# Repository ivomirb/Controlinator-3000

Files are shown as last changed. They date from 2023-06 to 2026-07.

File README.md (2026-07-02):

# Controlinator 3000
CNC handheld pendant for OpenBuilds CONTROL

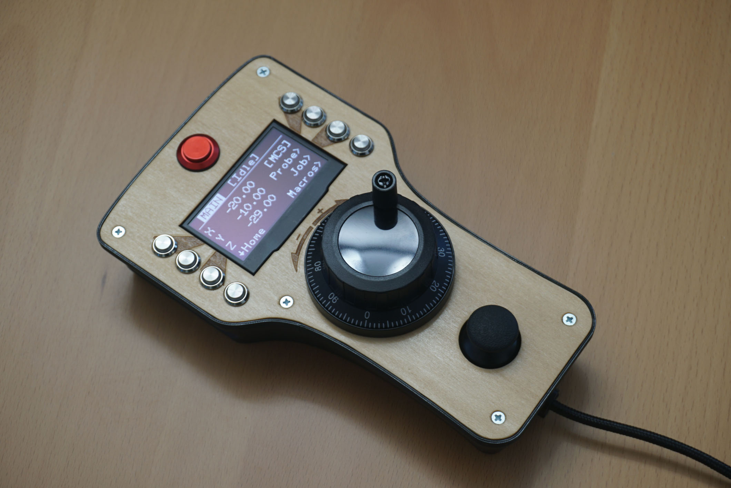
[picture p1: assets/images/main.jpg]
The pendant


## Main features

* Display current status and position
* Switch between machine and work coordinates
* Fast XY jogging with the joystick
* Precise jogging of a single axis with the handwheel
* Safe jog limits in all directions
* Start and control jobs, adjust feeds and speeds on the fly
* Run custom macros
* Probe Z
* Measure tool length
* Extensive configuration settings

## Documentation

How to make it: [/docs/hardware.md](/docs/hardware.md)

How to program it: [/docs/software.md](/docs/software.md)

How to configure it: [/docs/settings.md](/docs/settings.md)

How to use it: [/docs/usage.md](/docs/usage.md)

Tool length probing: [/docs/tool_length.md](/docs/tool_length.md)

Issues and future developments: [/docs/future.md](/docs/future.md)

## Versions

### 1.5 - July 2026
* Added support for Arduino Nano R4
* The joystick can be used on the probing screen to nudge the XY position
* Holding down Z on the jog screen moves up
* NOTE: Requires OpenBuilds v1.0.371 or later

### 1.3 - June 2026
* Few bug fixes
* Job actions (run, pause, stop) are logged to the console
* Improved diagnostics for disconnects and freezes
* Randomize tool probe location to reduce surface wear

### 1.2 - August 2025
* New option to use the probe to measure Z height without changing the work coordinate system
* A watchdog system to detect lockups and automatically restart and reconnect
* Few bug fixes

### 1.1 - July 2023
* Initial public version

## Few videos of the pendant in action
Higher-quality versions of these videos can be viewed near the bottom of the OSHWLab page: https://oshwlab.com/ivo1/controlinator3000

https://github.com/ivomirb/Controlinator-3000/assets/85206280/82b60430-23b6-44c3-90c5-cbde8dea85b0

https://github.com/ivomirb/Controlinator-3000/assets/85206280/08690167-5684-4be5-bea4-8ef6c2ea5f81

https://github.com/ivomirb/Controlinator-3000/assets/85206280/ce256c9c-9cf2-4aa7-af1b-1ccd04ead18f

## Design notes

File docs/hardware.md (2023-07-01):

# Controlinator 3000 - Hardware

Long story short, make the PCB, add a microcontroller, a display, some buttons, a handwheel and a joystick. Place them inside the provided 3D model. Upload the C++ code to the microcontroller and use the Javascript code as a macro for the OpenBuilds Control software.

You can use Arduino Nano, Arduino Nano Every with 4809 chip, or Arduino Nano clone with 4808. The last two have extra memory, which enables better performance.  
Schematic: https://easyeda.com/editor#id=6772a173c7f747c4bd99ec3e6c18ea2e  
PCB: https://easyeda.com/editor#id=7d417a9957d24bc288f2ec065d723912  
Source code: https://github.com/ivomirb/Controlinator-3000/tree/master/Source  
3D models: https://github.com/ivomirb/Controlinator-3000/tree/master/Models

## Components

**Microcontroller:** You need one compatible with Arduino Nano. There are few options with different capabilities. Both 30-pin and 34-pin packages are supported. See the next section for more details.

**Display:** A 2.4” OLED display compatible with the I2C interface. This is the one I used: https://www.aliexpress.us/item/3256805055000425.html  
**Note:** This particular model requires hardware modification to work correctly. Remove the D2 diode and replace it with a straight wire. Without this it won’t send the ACK signal and it will only work in software mode, which is slow. In my experience most similar screens come in SPI mode out of the box and require hardware modifications to convert to I2C. It is possible to redesign the pendant to use SPI, with some modifications to the PCB design and using an extra digital pin

**Handwheel:** A manual pulse generator like this: https://www.aliexpress.us/item/2251832666651590.html  
You need the 5V version to be compatible with the Arduino. The 4-pin version works best. If you have the 6-pin version it will also work, just ignore the bottom two connectors.  
I actually ended up using the plastic version from here: https://www.aliexpress.us/item/3256801157578368.html  
It is half the weight of the metal wheel (80 grams vs 160), reducing the overall weight of the pendant by 20%

**Joystick:** I am using a regular Arduino joystick that you can find everywhere. Here’s one example: https://www.aliexpress.us/item/2251832496927403.html

**Buttons:** You need eight 8mm buttons. They are the smallest ones I could find that still feel like regular buttons. Also one 16mm button for the Self Destruct at the top. It can be red for dramatic effect  
https://www.aliexpress.us/item/3256801900884791.html  
https://www.aliexpress.us/item/3256804994691187.html

**Optional reset switch:** You can mount a tiny reset switch that is accessible through a small hole in the front. The existing mount is for this type of switch: https://www.amazon.com/gp/product/B073TYWX86

You can find the schematics here: https://easyeda.com/editor#id=6772a173c7f747c4bd99ec3e6c18ea2e  
Shoutout to EasyEDA – I’ve never designed a PCB before, but after only watching a [10-minute video](https://www.youtube.com/watch?v=MsdJgEinb34) I was able to make my own circuit, edit a custom footprint for the 34-pin Arduino variant, design the dual layer board, and order it from the JLCPCB factory, all in two hours. With the available coupons, I got 15 copies essentially for free.  
(not a sponsored statement – just happy with the service and the end product)

## Microcontrollers
There are few choices that are supported

1. A regular Arduino Nano with ATmega 328P. It has 32K ROM and 2K RAM. This is what I used throughout most of the development

2. Arduino Nano Every, with ATmega 4809 chip. It has 48K ROM and 6K RAM. The extra memory allows for the display to be mirrored in RAM and to be updated only as needed. This greatly improves the framerate and responsiveness.  
I do not own one and haven’t tested it, however I’m pretty confident it would work, since it is very similar to 4808

3. An Arduino Every clone with ATmega 4808, like this one: https://www.aliexpress.us/item/3256804681280426.html  
It is similar to Arduino Every, however has 4 extra pins, including a UPDI connection that allows programming it without interfering with the USB port. This is what I ended up using in the final version.  
**Note:** While this model has the same general pinout as Arduino Nano, there are subtle differences. The most notable is that the SCL and SDA pins needed to drive the display are on different pins – D4 and D5 instead of A4 and A5 on the Nano. The PCB can be configured to work with one or the other. See below

Other devices may also work if they have the right capabilities and compatible pinout. You may need to edit Config.h to be able to compile the source code.

## Assembly
* If you have a 30-pin Arduino Nano or Nano Every, use the middle 30 pins. Ignore the 4 corner pins. For 34-pin versions use the entire footprint

* You can solder the Arduino directly to the PCB or use two 17-pin female headers to make it removable. I opted for removable so I can easily experiment during development

* Under the Arduino there are 6 pads that route the SCL and SDA signals for the display. Use two pieces of wire to bridge the middle pads to the left or to the right, depending on your microcontroller. Standard Arduino Nano and Every use the A4 and A5 pins (connect middle and right). The 4808 version uses D4 and D5 (connect middle and left). Check the documentation for your exact device.
I am using a 3x2 right-angle pin header, which allows me to select one or the other with jumpers during development

* **Optional step:** 34-pin versions have an extra programing pin in the top-left. If you want to use it, add a 4.7K resistor to R1 and a 2-pin header to UPDI. Look up “UPDI” online to find tutorials how to use it. If your programming circuit already includes a resistor, replace R1 with a piece of wire

* **Optional step:** Normally the Arduino would reset if a serial connection is initiated from the PC. This is to allow it to be programmed, however it causes a few seconds delay before it is operational. To avoid that, add a 100nF capacitor to C1 and a 2-pin header to JMP. Then use a jumper on the header to disable the reset. Remove the jumper during programming. If you only use the UPDI for programing, you may short the JMP pads with a piece of wire permanently

* **Optional step:** RST is for wiring an external reset switch. In my case I have a tiny switch at the front of the pendant, which can be pushed through a small hole with a paperclip

* DISP is for wiring the display. The pins are GND, 5V, 3.3V, SCL, SDA. Use either the 5V or the 3.3V pin depending on the power requirements for your particular model. The display I have worked with either voltage. Only use one of the two – don’t short them together

* Connect a 4x2 right-angle pin header to BTN1..4. This is for the buttons on the left side of the pendant. Right-angle headers allow for a slimmer profile

* Connect a 5x2 right-angle pin header to BTN5..9. This is for the 4 buttons on the right side and for the big Abort button at the top. You can also use a 6x2 header, which exposes pin D11 for expansions

* MPG is for the handwheel

* JOY is for the joystick. The X and Y are marked according to the joystick device, but are reversed in software to account for the mounting orientation

* You can technically solder everything permanently, but I prefer to have cables that are detachable from one end to ease the assembly and disassembly. I have the display and joystick wires soldered to the board with Dupont connector on the other end. The handwheel wires are soldered to the board with spade connectors on the other end. The button wires are soldered to the buttons and connect to the corresponding headers on the board

When assembled, the PCB should look like this:

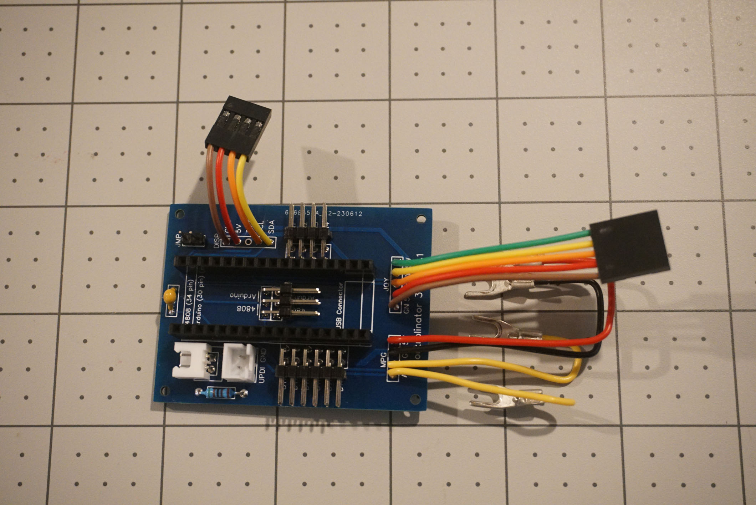
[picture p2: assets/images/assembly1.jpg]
Assembled PCB


You can find the 3D printed parts here, both as STL and STP: https://github.com/ivomirb/Controlinator-3000/tree/master/Models

You can use the face plate as is, or print it 1.5mm thinner and add a layer of thin plywood on top. I myself used basswood sprayed with shellac. Use the face_plate.svg file for the shape.

There are 2 versions of the PCB bracket – one for a prototype 40x60mm board and one for the custom PCB from EasyEDA. The hole spacing is different. The bracket assumes that the display connectors are on the right side. You will need to modify the model if your screen has its pins someplace else.

The large parts can be printed at 0.3mm layer height and the small pieces at 0.1. I use PETG for everything. I find it durable and it has a bit of a flex that holds screws well.

Attach the PCB to the top of the bracket using 2mm machine screws and 4 of the spacers. Then screw the screen to the bottom and connect the cable.

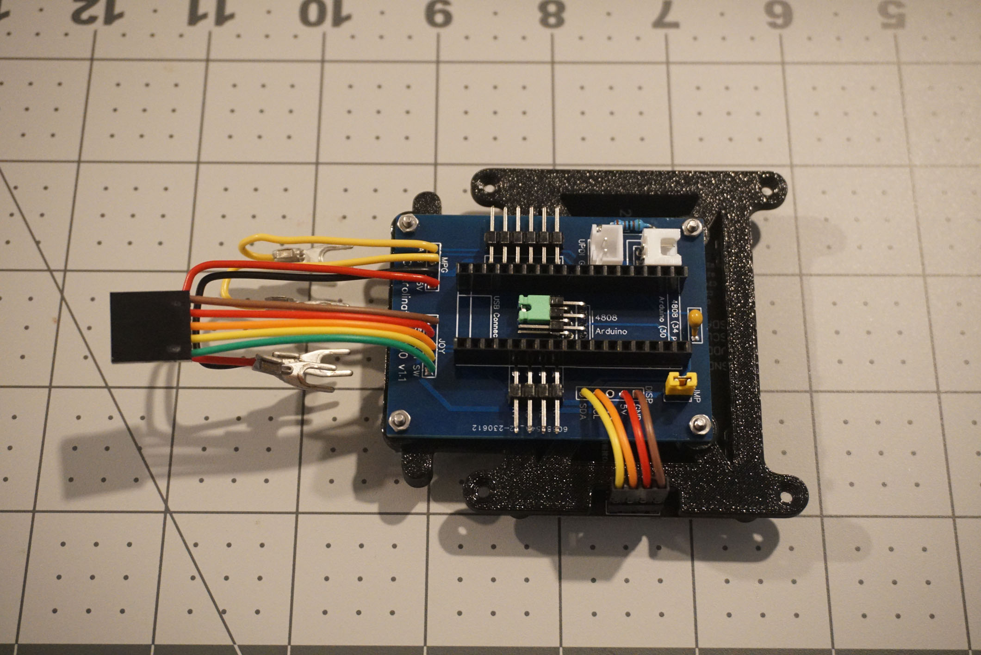
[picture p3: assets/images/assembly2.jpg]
Assembled PCB and display


The joystick and the screen attach with 2mm wood screws. I used these: https://www.amazon.com/gp/product/B0768H7HTR
The cable clamps and the final assembly of the box use standard 3/4" #4 wood screws.
The reset switch uses 2mm machine screws and threaded inserts that are embedded in the plastic.

You can use different size screws, but you may need to adjust the holes in the 3D models to match.

You will also need a USB cable of some sort. I recommend 6-10 feet long. It needs to match the connector of your microcontroller. It could be micro-USB, mini, or even USB-C.

The cable is held in place by the two halves of the cable holder, connected with M3 screws and 5.5mm square nuts.

Here’s everything put together:

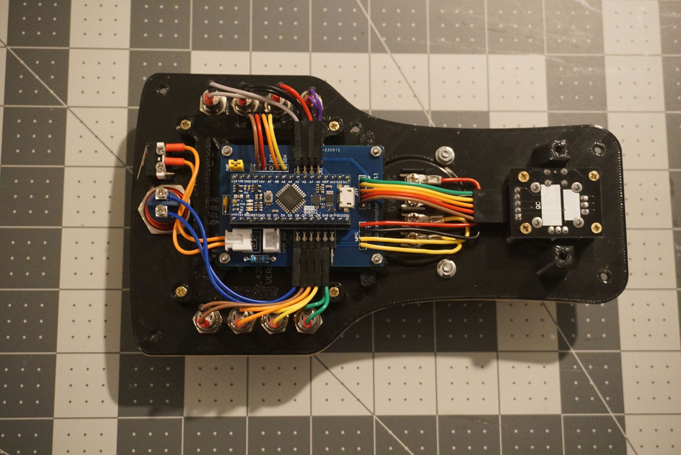
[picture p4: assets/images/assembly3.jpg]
Assembled pendant


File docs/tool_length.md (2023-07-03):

# Controlinator 3000 - Tool length

When a job uses multiple tools, you have to ensure that the Z position is preserved from one tool to the next. Probing for Z is not always an option, and is error-prone. The best way is to adjust the tool length offset (TLO) as the tool is replaced.

The TLO implementation in Grbl is not that good. You can set the value, however it is lost after a soft reset, which can happen quite often. There is very little indication when that happens.

The pendant software uses different approach to adjust the Z offset when the tool is changed. It requires a tool sensor to be installed on the CNC. A tool sensor is nothing more than a Z probe at a fixed location. In the pendant settings, enter the X and Y location of the sensor and select the probing method. The settings are similar to the Z probe.

You start your job as normal with the first tool. Use the regular Z probe to measure your work piece. Before switching to the second tool, select the Probe option from the main menu on the pendant, then select "Probe Ref Tool". You will use the tool sensor to measure the absolute height of the current tool. It will become the reference for all future tools.

Replace the tool in the spindle, and then select "Probe New Tool". The pendant will measure the new tool, determine the difference in the length compared to the reference tool, and will apply the difference to the current Z offset.

If you ever forget to probe the next tool and lose your reference, you will need to select "Probe Ref Tool" again. As long as you have a tool that matches your current work coordinate system, you can successfully use it as a reference for future tools.  
**Note:** the reference height will be lost if the OpenBuilds software restarts. Again, just make sure you have correct work Z, and set the current tool as a reference.

Since the pendant software will jog to the tool sensor location in machine coordinates, it requires that the machine is homed. If the pendant thinks that the machine has lost its homing position, it will show a warning message. You can ignore it if you think it is safe.

## Tool Sensor Variants

There are different ways to create a tool sensor. The important thing is that the sensor doesn't move between measurements.  
The sensor will be connected in parallel with the regular Z probe, meaning it will trigger the Z probe signal when the tool touches the sensor.

Here are few possible ways to do it:

1. Use a regular Z probe plate that is securely attached somewhere. You will need to connect the alligator cable to your spindle every time you measure the tool.

2. Use an off the shelf tool sensor, maybe something like this one: https://www.amazon.com/RATTMMOTOR-Automatic-Normally-Setting-Engraving/dp/B08LK93NTC  
I have not tried such a device myself. Those are nice as they have a secondary contact that is triggered if the button is pushed too far. You can wire it to the E-Stop to shut down everything before any damage is done. There is also an option to connect compressed air to blow the chips off of the tool during probing.

3. Make one yourself using a push button. This is what I ended up with.  
The advantage of using a button over Z plate is that you don't need to connect the alligator cable. You can have the sensor out of the way in the far corner of the machine.
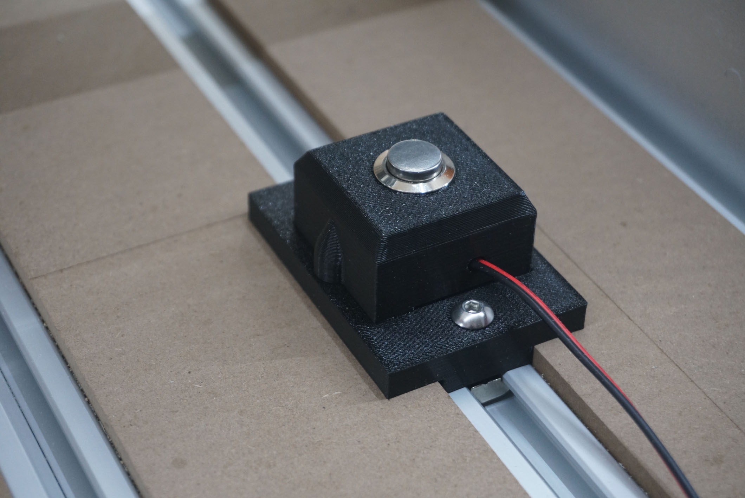
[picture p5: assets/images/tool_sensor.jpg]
Tool sensor


You can find the 3D models here: https://github.com/ivomirb/Controlinator-3000/tree/master/Models  
There is a top and bottom part, connected with M3 threaded inserts.  
It uses a 16mm push button like this one: https://www.aliexpress.us/item/2251832680756878.html  
A larger button will work even better because it will be able to handle larger tools, like a spoilboard flattening cutter.

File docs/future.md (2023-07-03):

# Issues and future developments

There are a few things that can be improved in future versions. In no particular order:

There is a known problem where jogging with the wheel might occasionally stall. This happens when Grbl enters a Run state instead of Jog state after a jog command. The next jog command fails, because jog commands are not allowed during the Run state.  
At this time I don't know if this is a bug in Grbl or something my code is doing wrong.

You can use buttons with built-in lights. This way the buttons that are inactive can be turned off, making it easier to associate a button with its label, even if they are not exactly aligned. There aren’t enough pins to control each light individually, however an 8-bit shift register like 74HC595 can be used to drive 8 LEDs with only 3 digital pins.

I would have liked a handwheel with fewer number of clicks per rotation for greater precision. The commonly available optical rotary encoders have 100 clicks. Even the “25 pulses per rotation” models still have 100 mechanical clicks, which is kind of useless.

A move from 8-bit Arduino to a more powerful microcontroller like ESP32 can improve the frame rate and responsiveness. A faster chip could be able to drive a larger TFT screen as well. They usually run at 3.3V, so some extra circuitry will be needed to interface with the 5V handwheel signal.

ESP32 boards come with Wi-Fi and other connectivity features, opening the possibility for a wireless pendant.

A buzzer could be added to warn about dangerous operations, inform of alarms, or confirm a button press. The PCB exposes pin D11 for such extensions.

The commonly available small joysticks have a very large outer dead zone. Basically, pushing the stick half-way maxes out the output and pushing it further doesn’t have any effect. I tried comparing samples from different suppliers and they all have the same problem. Likely they all use the same potentiometers. There may be better models out there. Possibly a higher-quality joystick can be salvaged from a game controller.

Instead of a handheld pendant, you may create a box that is attached to your CNC permanently. Change the layout of the controls to serve your design.

Currently the pendant is only compatible with OpenBuilds Control. It is possible to port the Javascript macro to other platforms that supports plugins. For example UGS can have plugins written in Java and bCNC can be extended with Python.

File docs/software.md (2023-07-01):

# Controlinator 3000 - Software

The source code can be found here: https://github.com/ivomirb/Controlinator-3000  
It is published under the MIT public license.

All code is included except for the U8G2 library. You will need to install it separately in the Arduino IDE.  
If you are using a different pulse encoder wheel, you might need to install this library as well: https://github.com/gfvalvo/NewEncoder  
The Controlinator source code contains a trimmed-down version of that library that is limited to support one type of wheel devices.

Compile the code, and then upload it with the USB cable or the UPDI port. Be careful of the polarity when connecting the UPDI. If you plug it in backwards, the microcontroller will likely be safe because of the resistor, however your programmer device will be shorted to ground and may get damaged.

On the OpenBuilds side, create a new Javascript macro and paste the contents of PendantMacro.js inside it. Set the macro to auto-start and then restart OpenBuilds from the tray icon.

## Javascript settings
At the top of the Javascript file you will find a few values to fine tune the behavior. Read the comments and decide if you wish to change them.

## C++ settings
Look at the Config.h file for a few available settings. You can configure the code based on the available memory and what kind of performance you are looking for.

## Pendant emulator

The emulator is a Desktop application that emulates the physical controls of the device and shares the majority of the code with the microcontroller. This allows for faster development using Visual Studio as editor and debugger.

The emulator also contains a piece of code that generates font.h from the font bitmap. You need to run it if you change the font or add more special symbols.

You will need to establish a serial connection between OpenBuilds and the emulator. I used a software called “HHD Virtual Serial Port Tools” to create a pair of connected ports COM13 and COM14. The emulator runs on COM14 (hard-coded in Serial.cpp) and the Javascript macro connects on COM13.  
There is another software “com0com” which should provide similar functionality, though I was unable to get it to work.

An even more lazy solution is to eliminate the CNC altogether. I uploaded a version of Grbl onto a standalone Arduino. OpenBuilds recognizes it as a valid machine. You can use the 3d view and other controls in OpenBuilds to monitor the current state of that virtual CNC.

Of course, emulation is not the same as the real thing, and final testing should be done with the actual pendant and a real CNC machine. But it is quite sufficient for building the user interface and for coding the first pass of the functionality.

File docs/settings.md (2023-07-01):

# Controlinator 3000 - Settings

Once the macro is running, it will add a Pendant button to the toolbar. From there you can connect the device, disconnect it, and edit the settings.

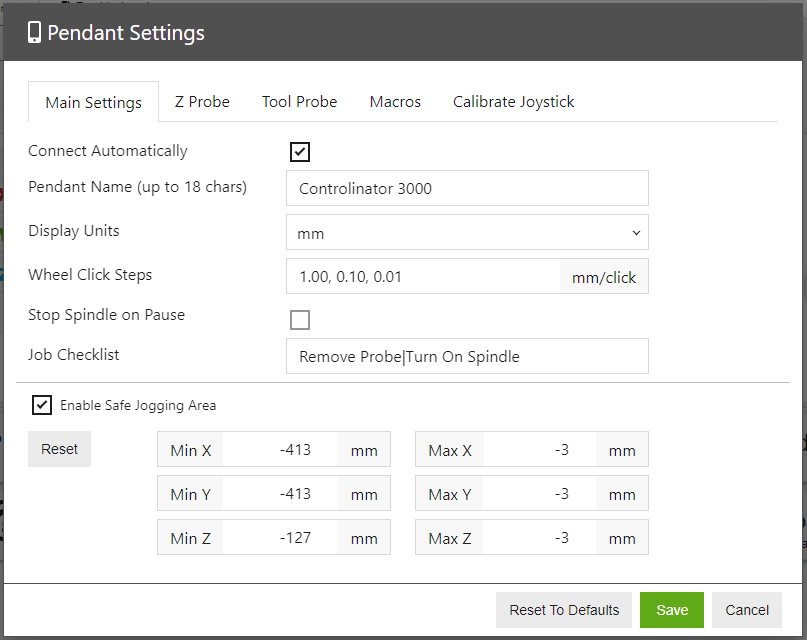
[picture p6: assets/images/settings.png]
Pendant settings


## Main Settings
**Connect Automatically** – check it if you want the pendant to auto-connect when OpenBuilds starts up

**Pendant Name** – set a name to be displayed on the pendant’s title screen. This can only be edited when the pendant is connected. The name is stored in the pendant’s EEPROM

**Display Units** – select if the pendant display should show the coordinates in inches or millimeters. It also affects the units for the wheel jog rate. It doesn’t change any other units in the pendant settings, which area always in mm

**Wheel Click Steps** – enter a list of movement distances for each click of the hand wheel. You can cycle between them using the Step button on the pendant. They don’t necessarily need to be in order. Pick an order that works for you, assuming that the first value in the list will be selected on startup

**Stop Spindle on Pause** – when this is enabled, pausing a job from the pendant (but not from the OpenBuilds toolbar) will automatically stop the spindle. This is done by triggering the door alarm in Grbl. Depending on the Grbl configuration, it may also raise the spindle to the park height. When you resume the job, the spindle will spin up for 4 seconds before it starts to move

**Jog Checklist** – enter up to 3 reminders to be shown on the pendant when you start a job. You will need to click the corresponding button to check off each one before you can continue

**Enable Safe Jogging Area** – this allows you to set an area in machine coordinates that is considered safe for jogging. Movement with the handwheel or the joystick will keep the machine inside the safe range

## Z Probe
**Z Probe Sequence** – select from “Single Pass”, “Dual Pass” or “Use default dialog”. Single and Dual pass allow you to select the travel distance and feed rate for the probe operation. Dual pass does 2 probings at different feed rates to improve accuracy.
When “Use default dialog” is selected, initiating a probe operation from the pendant will open the default dialog in OpenBuilds. It will allow you to use the extra settings for more complicated probing operations that are not available via the pendant alone. Of course, you will need to interact with the PC to access the extra settings

**Down Jog Speed** – select an override % rate for lowering the tool when the Z Down button is pressed on the pendant. Pick a speed that allows you to get close to the probe safely without running into it. The Z Up button is always at full speed because it is considered safe to go up

**Plate Thickness** – enter the thickness of your Z probe plate

**Use Exact Probe Result** – when probing, after the tool touches the probe, it would continue to travel for a few more steps before it stops. Open Builds and most other Grbl software use the final stop height. Check this box to use the original touch height instead. It can be more accurate

**Seek/Retract** – enter the travel distance and feed rate for each of the phases of the Z probing sequence

## Tool Probe
**Tool Probe Sequence** – choose between “Disabled”, “Single Pass” and “Dual Pass”. Single and Dual pass work the same way as in the Z probe settings

**Probe Location** – enter the X and Y location in machine coordinates of your tool sensor. Enter a safe Z location for approaching the sensor. When measuring the tool, the pendant will raise to Z first, then jog to the X/Y location right above the sensor

## Macros
Select up to 7 existing OpenBuilds macros to activate from the pendant. Enter the name of the macro in the first column. Auto-complete should help you find the right name.

Enter a short label in the second column. This is the name you will see on the pendant. There is limited space, so only 8 characters are allowed. If you leave it blank, you will get a generic name MACRO1, MACRO2, and such.

If you check the Hold checkbox, the pendant will require you to press and hold the button for 1 second before the macro is activated. Use this for dangerous operations that should not be triggered accidentally.

**Note on interactive macros:** Even though the pendant is limited to 7 macros, you can create powerful Javascript macros that can offer a lot of functionality. Use the following code:
`var ShowPendantDialog = $('#pendant').prop('ShowDialog');`
This will allow the macro to use the `ShowPendantDialog` function that shows a message on the pendant with 2 button options. Search for ShowPendantDialog in PendantMacro.js for documentation on how to use it and to find a few examples.

## Calibrate Joystick
This page allows you to calibrate the joystick. It shows the current joystick X and Y values, ranging from 0 to 1023. The green box shows the area that the joystick can reach. The red box is the inner dead zone, where the joystick is considered to be at rest.

You can edit the values manually at the bottom.

You can click the Calibrate Joystick button, which will begin the calibration sequence.

First, move the joystick to all extremes, and press OK on the pendant. This will determine how far the joystick can reach.

Afterwards, there are 8 tests to determine the dead zone. Push the stick away, then release it, then press OK. Do this a few times in different directions.

The calibration page is only available when the pendant is connected. The calibration values are stored in the pendant’s EEPROM, as they are tied to the actual joystick hardware.

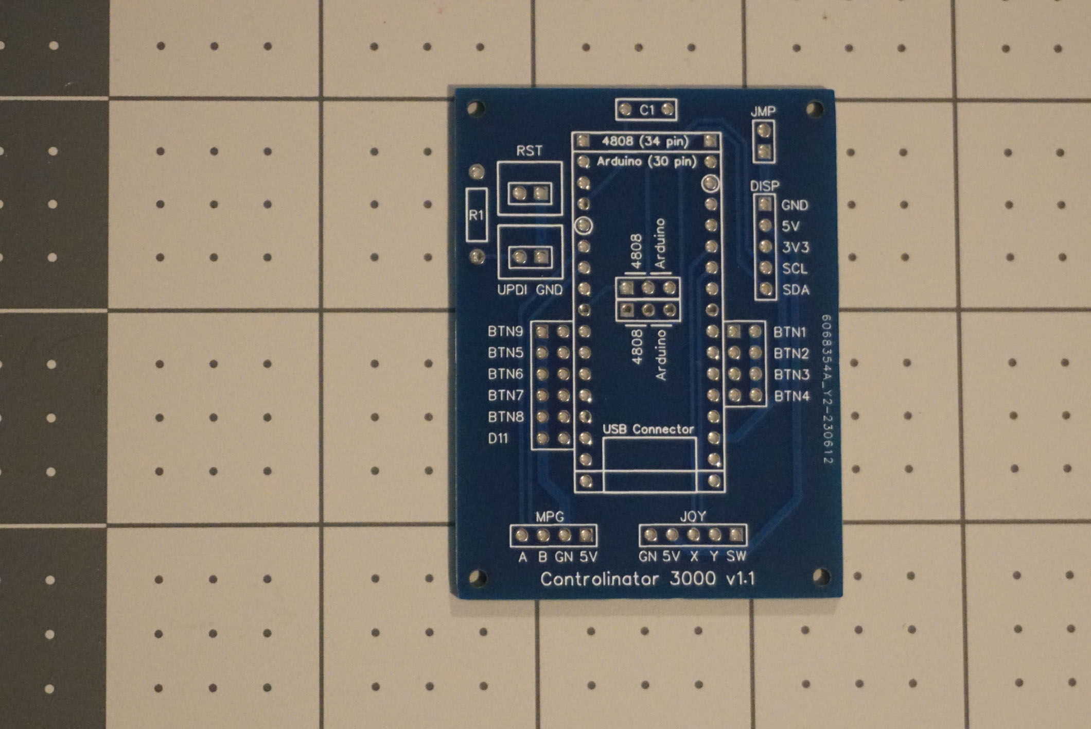
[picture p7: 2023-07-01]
assets/images/new_pcb.jpg

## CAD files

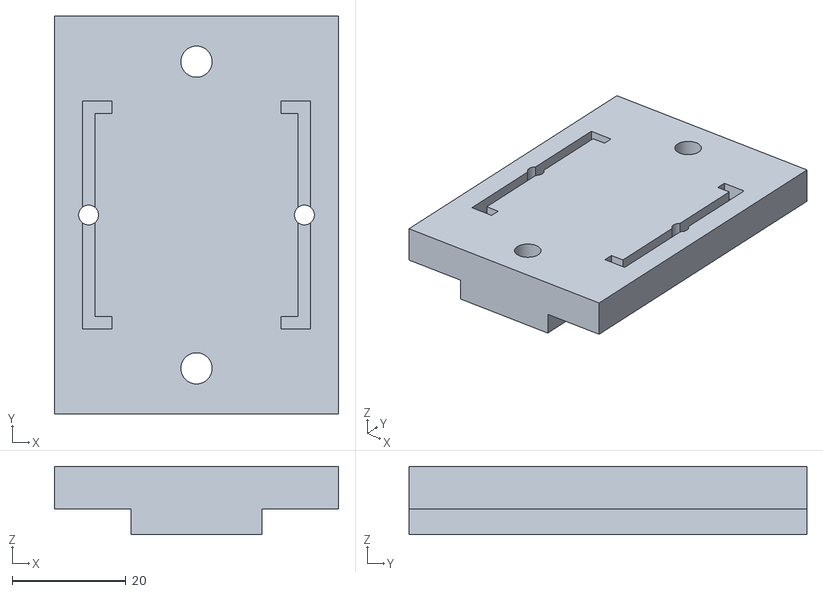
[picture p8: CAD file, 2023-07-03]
Models/tool_sensor_base.stl
50.0 x 70.0 x 12.0

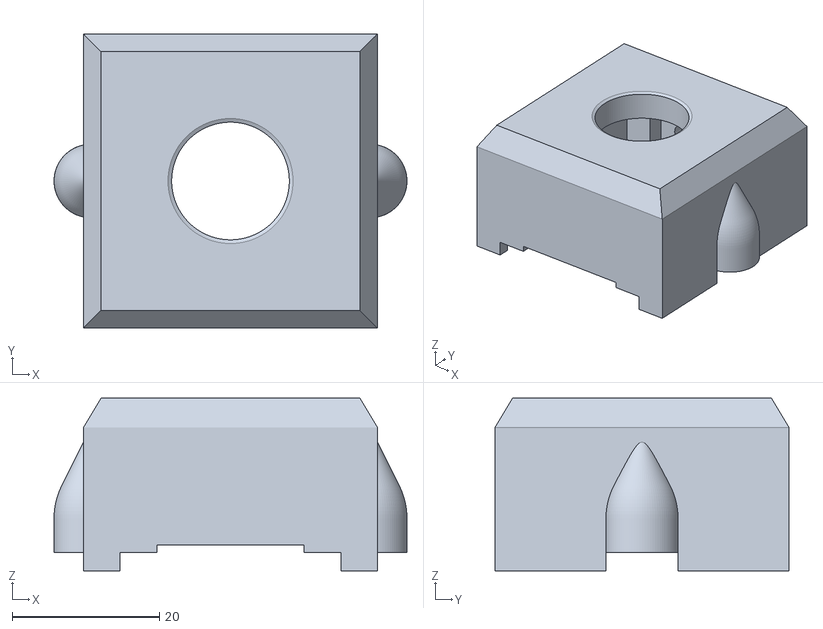
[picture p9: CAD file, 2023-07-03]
Models/tool_sensor_top.stl
48.0 x 40.0 x 23.5

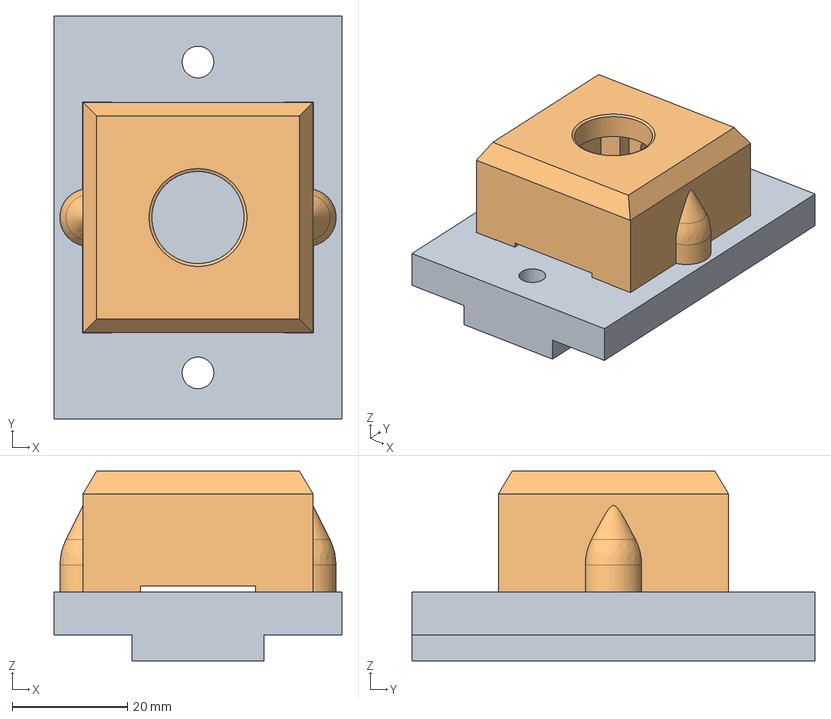
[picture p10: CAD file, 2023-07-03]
Models/tool_sensor.step
50.0 x 70.0 x 33.0 mm

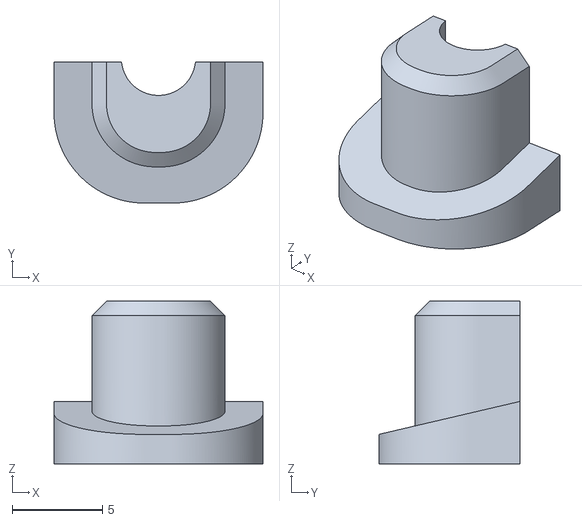
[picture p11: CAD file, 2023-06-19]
Models/grommet_top.stl
11.6 x 7.80 x 9.00

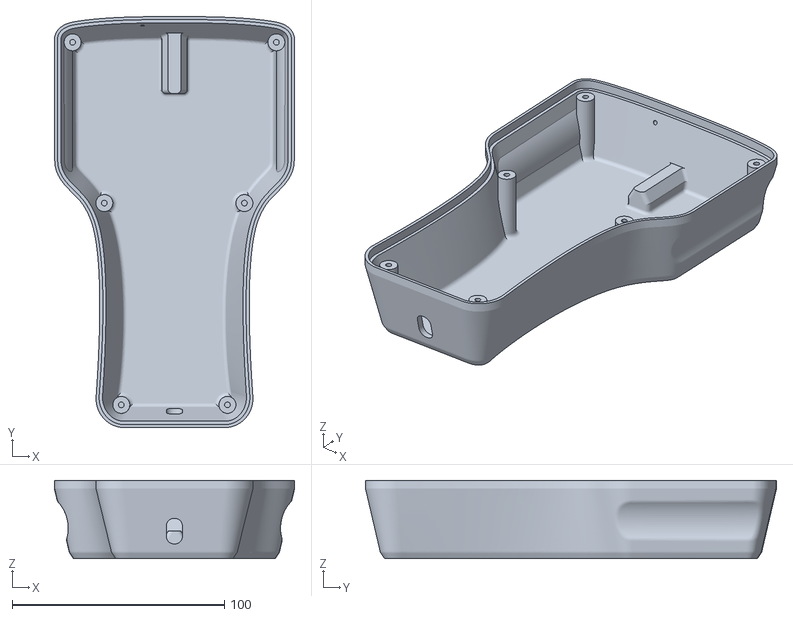
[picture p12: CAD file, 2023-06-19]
Models/shell.stl
113.3 x 193.8 x 37.0

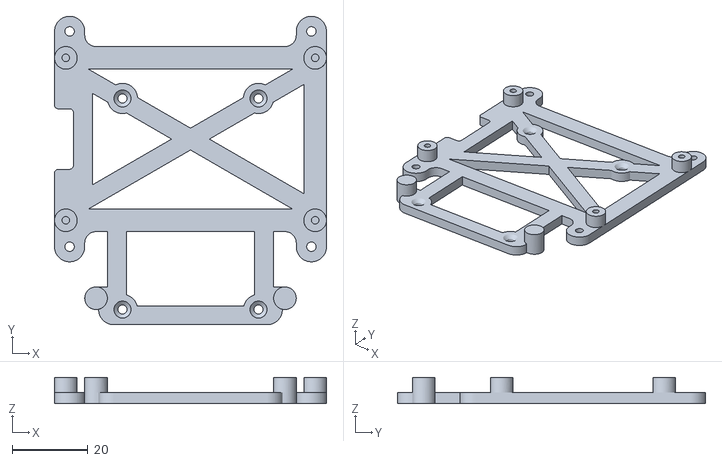
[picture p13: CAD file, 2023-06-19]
Models/pcb_mount_40x60.stl
72.0 x 81.6 x 7.00

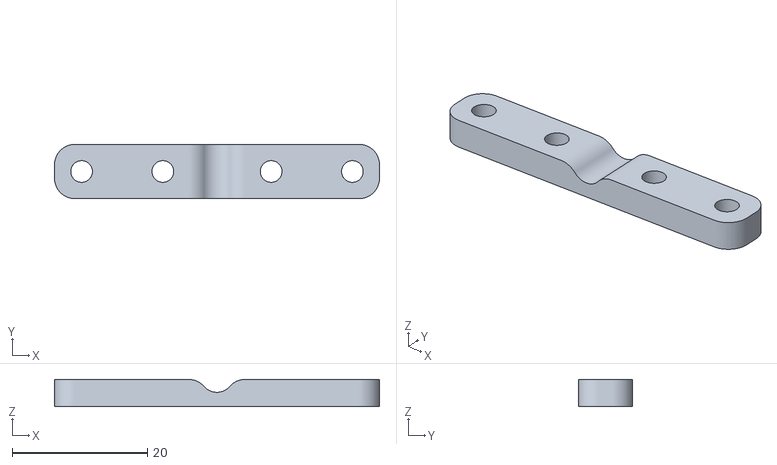
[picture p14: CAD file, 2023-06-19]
Models/cable_clamp_bottom.stl
48.0 x 8.00 x 4.00

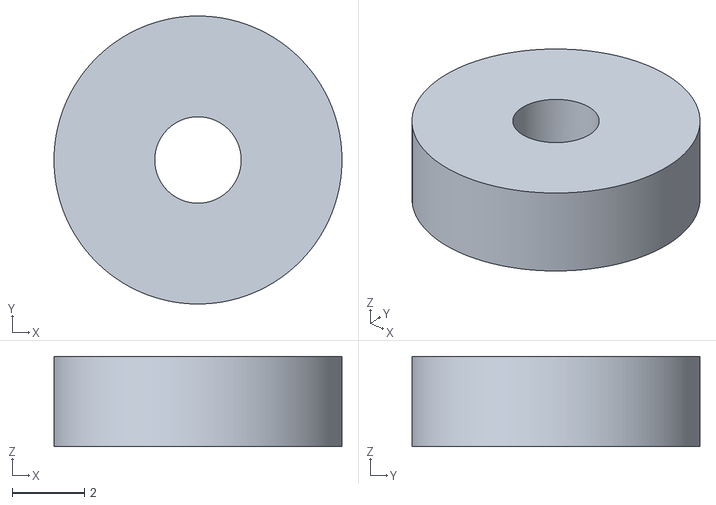
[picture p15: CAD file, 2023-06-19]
Models/pcb_standoff.stl
8.00 x 8.00 x 2.50

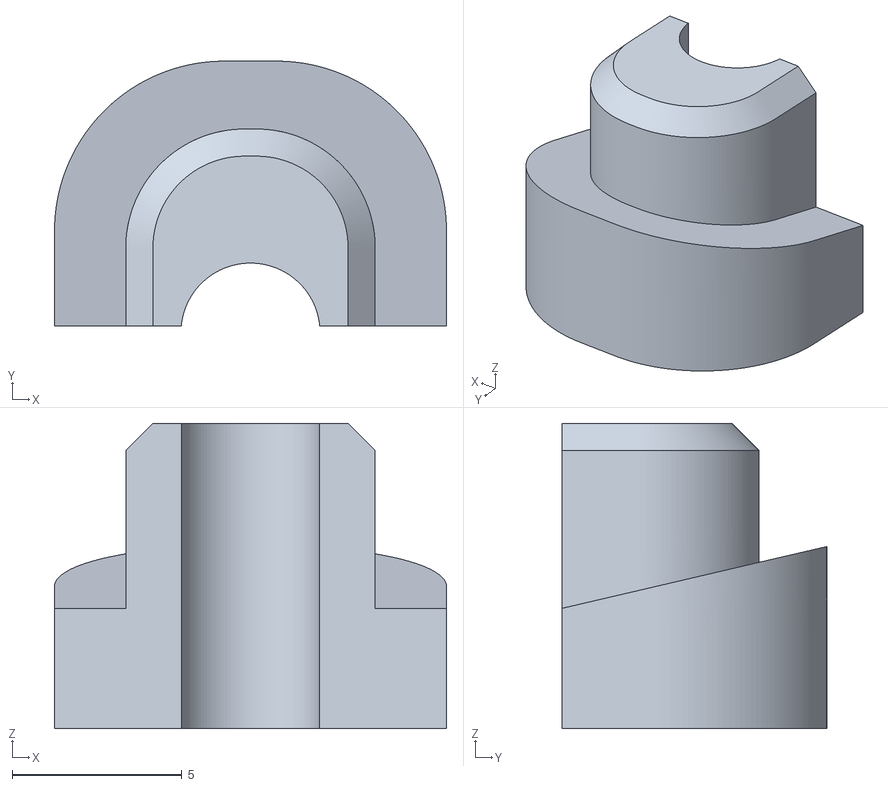
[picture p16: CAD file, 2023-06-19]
Models/grommet_bottom.stl
11.6 x 7.80 x 9.00

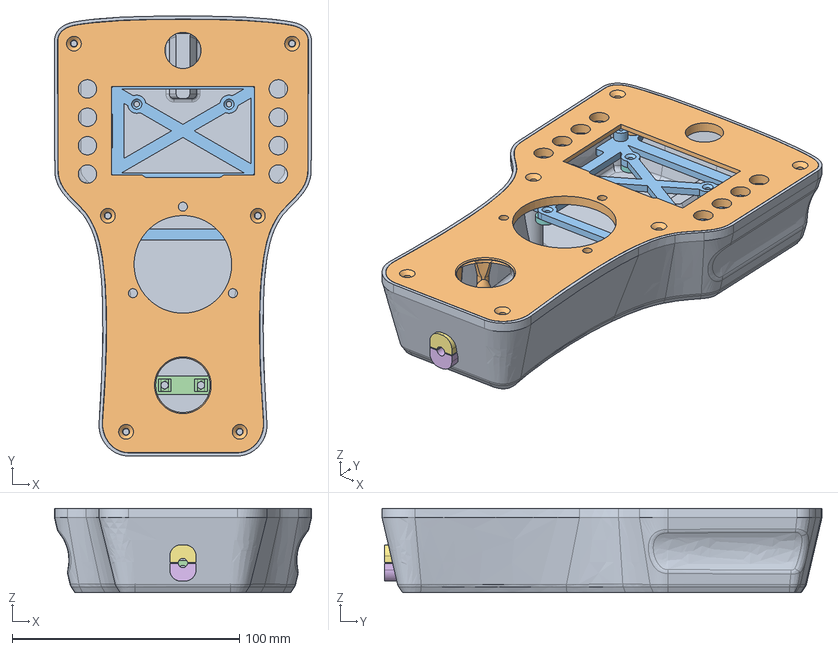
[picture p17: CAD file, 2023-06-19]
Models/Controlinator3000.step
113.3 x 193.8 x 37.0 mm

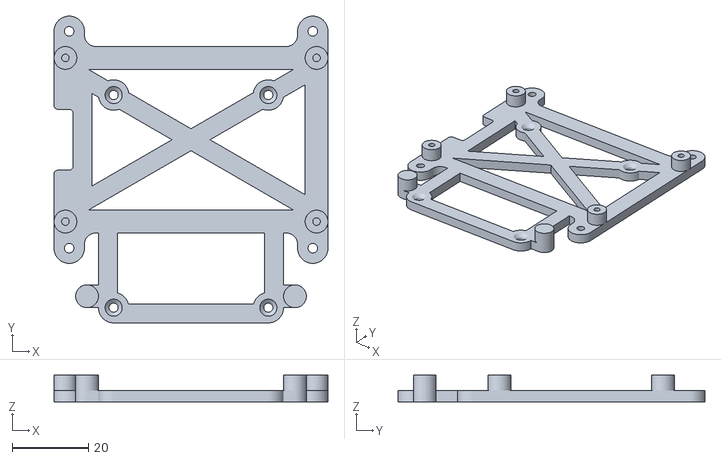
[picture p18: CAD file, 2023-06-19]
Models/pcb_mount.stl
72.0 x 80.6 x 7.00

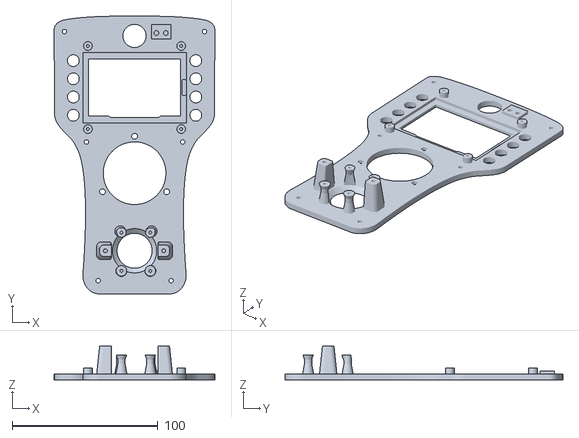
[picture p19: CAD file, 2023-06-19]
Models/face.stl
110.2 x 190.8 x 23.0

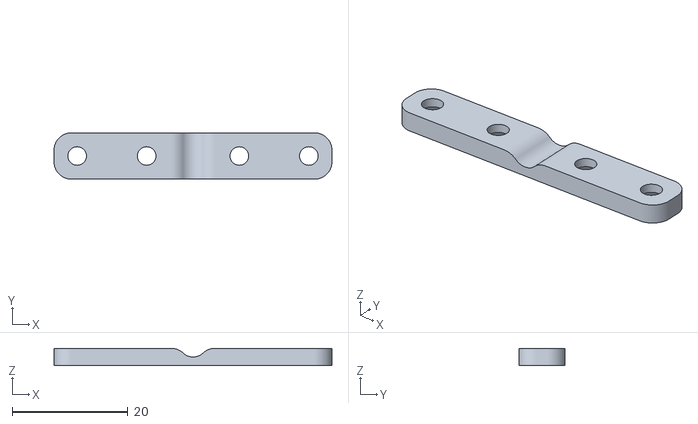
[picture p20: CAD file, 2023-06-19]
Models/cable_clamp_top.stl
48.0 x 8.00 x 3.00

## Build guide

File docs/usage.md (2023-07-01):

# Controlinator 3000 - Usage

Here’s an explanation of most of the pendant screens and how to operate them.

As a general rule, if a button label has a down arrow next to it, then it requires the button to be pressed for 1 second to activate. A button with the > symbol opens a sub-menu.

The top of most screens shows the current machine status (Idle, Jog, Run).

## Main screen
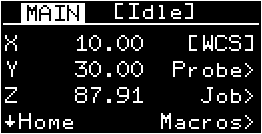
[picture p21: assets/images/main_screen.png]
Main screen


It shows the current X/Y/Z values. Use the **[MCS]/[WCS]** button in the top-right to switch between machine and work coordinates.

Press and hold the Home button to initiate homing. If the machine is considered already homed, then you will be asked to confirm if you want to do this again.

Press **X**, **Y** or **Z** button to enter jog mode.

Press the joystick button, or X and Y at the same time to enter joystick jog mode.

Press **Probe**, **Job** or **Macro** to enter the corresponding sub-menus.

## Jog screen
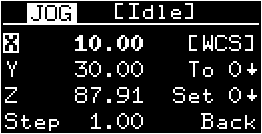
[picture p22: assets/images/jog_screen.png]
Jog screen


If you select X, Y or Z, you are in single axis jog mode. Use the wheel to move the selected axis by discrete increments dependent on the current rate.

Short click the **Step** button to cycle between the available step options. They are configurable from the settings.

Long click on the **Step** button will align the axis to the nearest multiple of the step value. For example if you have selected 0.50 mm, then it will round to the nearest half millimeter. The rounding depends on the currently selected coordinate system. A rounded value in one of them is not necessarily round in in the other.

Press and hold **To 0** to jog to the origin of that axis. The actual position depends on the currently selected coordinate system. If 0 is outside of the safe jogging area, the position will be limited to a safe value.

Press and hold **Set 0** to set the current 0 for the axis. This is only available for the work coordinate system.

If you press both **X** and **Y** together, or if you click the joystick button, you will enter XY jog mode. Use the joystick to move.

If there is no input for 10 seconds, the jog screen will be dismissed and go back to the main screen. This is to avoid accidental movement when the pendant is put down.

## Probe screen
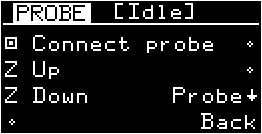
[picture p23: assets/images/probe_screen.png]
Probe screen


The probe screen allows you to measure the workpiece Z or the tool length. For the tool features to be available, they need to be configured from the settings and the machine needs to be homed.

Press the **Z Up** or **Z Down** buttons to move up and down. Be careful when moving down to avoid hitting something. There is a safety feature that will stop going down if the probe is touched, however it requires that the probe wire is connected and even then, there is still some latency that can cause damage.

Press and hold the **Probe** button to initiate the probe sequence. It can be a single pass or a dual pass, as selected from the settings.

When measuring a reference tool, the located Z value is simply remembered and doesn’t affect anything. When measuring a new tool, the new Z value will be subtracted from the reference tool and the difference will be applied to the work Z coordinate. This will allow you to retain the same work Z in relation to the new tool.

The reference value is retained by the PC for as long as the OpenBuilds software is running. If the software is closed, the value is lost and you will have to measure the current tool again as reference.

## Job screen
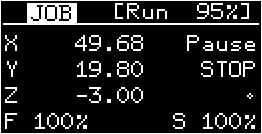
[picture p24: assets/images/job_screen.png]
Job screen


You can enter this screen from the main menu, either to start a new job or to manage one that is already running.

On the left it shows the current work space coordinates.

At the bottom you see the current Feed rate and Speed overrides (in percent). Press the corresponding button to select an override and then use the wheel to adjust the rates between 10% and 200%. This can be done before the job starts or while it is running.

The **Run** button starts the job. Hold down for 1 second to activate.

Press the **Pause** button to pause the job. This may also stop the spindle if it is configured in the settings. If not, you will get a button **RPM 0** which will allow you to stop the spindle while the job is paused.

Press and hold **Resume** to resume a paused job. If the spindle was stopped by the pendant, it will spin up for 4 seconds and then the movement will resume.

Press **STOP** to stop the job immediately.

## Macro screen

The macro screen allows you to execute up to 7 macro functions defined in the settings. Some buttons might require a press and hold before activating. Such items have the down arrow symbol.

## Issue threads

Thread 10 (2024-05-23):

LCD support

jon-daemon, 2024-05-23:
I'm thinking to build one but I think this particular display you used is too expensive. Is there any other cheaper alternative that I could use? I have found the ST7567S which is also I2C. Would that work with some modifications?

I have built something similar [here](https://github.com/jon-daemon/cncjs-pendant) but it's for CNCjs. I'd like to try yours to have the WCS position on the display. Also I don't use the joystick and I might eliminate that. The encoder works fine for me.

ivomirb, 2024-05-23:
A smaller screen will definitely work, as long as it has the necessary resolution. I wanted the largest screen I could find so it is easier on the eyes and so that the buttons will roughly match the text location. If reading the small text is not an issue for you, go for it.

The joystick is certainly optional. You should remove the code that reads the X and Y positions, or it will think that the joystick is pushed to the corner. Just remove the body of the function UpdateJoystick in input.h.

jon-daemon, 2024-05-24:
Thank you, I will try to build it with some modifications in the next month and report back.

Closed 2024-05-24.

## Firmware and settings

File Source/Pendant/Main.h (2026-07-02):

#define PENDANT_VERSION "1.5" // must match Pendant.js
#define PENDANT_BAUD_RATE 38400 // must match Pendant.js

#include "Config.h"

const uint8_t g_Font[] U8X8_PROGMEM =
{
#include "font.h"
};

char g_TextBuf[20];

#include "SpecialStrings.h"
#include "RomSettings.h"
#include "Graphics.h"
#include "Input.h"
#include "MachineStatus.h"

const unsigned long PING_TIME = 10000; // 10 seconds of no PONG will disconnect (could be shorter, but I noticed that when VSCode starts up, the COM traffic stalls for a few seconds)
const unsigned long SHOW_STOP_TIME = 500; // after 500ms after the last idle, allow showing s STOP button

///////////////////////////////////////////////////////////////////////////////
// State

bool g_bConnected;
bool g_bTimedOut;
#if USE_WATCHDOG
bool g_bWDTCrash;
#else
const bool g_bWDTCrash = false;
#endif

unsigned long g_CurrentTime;
unsigned long g_LastPingTime;
unsigned long g_LastPongTime;
unsigned long g_LastIdleTime;
unsigned long g_LastBusyTime;
bool g_bCanShowStop;

// coordinate systems
float g_WorkX, g_WorkY, g_WorkZ;
float g_OffsetX, g_OffsetY, g_OffsetZ; // machine = work + offset
bool g_bWorkSpace = true;
bool g_bShowInches = true;
bool g_bJobRunning = false;
bool g_bRecentlyHomed = false;
bool g_bProbeContact = true;
int8_t g_JobProgress = -1;

enum
{
	PROBE_MEASURE_ENABLED = 1,
	PROBE_TLO_ENABLED = 2,
	PROBE_TLO_HAS_REF = 4,
	PROBE_TLO_IN_POSITION = 8,
};

uint8_t g_ProbeState = 0;

// feed and speed
uint16_t g_FeedOverride;
uint16_t g_SpeedOverride;
uint16_t g_RealFeed;
uint16_t g_RealSpeed;

///////////////////////////////////////////////////////////////////////////////

#include "_BaseScreen.h"
BaseScreen *BaseScreen::s_pCurrentScreen;
#include "_ScreenClasses.h"

AlarmScreen g_AlarmScreen;
#ifndef DISABLE_CALIBRATION_SCREEN
CalibrationScreen g_CalibrationScreen;
#endif
DialogScreen g_DialogScreen;
JogScreen g_JogScreen;
#ifndef DISABLE_MACRO_SCREEN
MacroScreen g_MacroScreen;
#endif
MainScreen g_MainScreen;
ProbeMenuScreen g_ProbeMenuScreen;
RunScreen g_RunScreen;
#ifndef DISABLE_WELCOME_SCREEN
WelcomeScreen g_WelcomeScreen;
#endif
ZProbeScreen g_ZProbeScreen;

// This is outside of _BaseScreen.h because it needs access to the other screens
void BaseScreen::CloseScreen( void )
{
	if (IsActive())
	{
		if (!g_bConnected || g_MachineStatus == STATUS_DISCONNECTED)
		{
#ifndef DISABLE_WELCOME_SCREEN
			g_WelcomeScreen.Activate(g_CurrentTime);
#endif
		}
		else if (g_MachineStatus == STATUS_ALARM)
		{
			g_AlarmScreen.Activate(g_CurrentTime);
		}
		else
		{
			g_MainScreen.Activate(g_CurrentTime);
		}
	}
}

#include "AlarmScreen.h"
#include "CalibrationScreen.h"
#include "DialogScreen.h"
#include "JogScreen.h"
#include "MacroScreen.h"
#include "MainScreen.h"
#include "ProbeMenuScreen.h"
#include "RunScreen.h"
#include "WelcomeScreen.h"
#include "ZProbeScreen.h"

#if USE_WATCHDOG
#include "Watchdog.h"
#endif

///////////////////////////////////////////////////////////////////////////////

char g_SerialBuffer[128];
int g_SerialBufferLen = 0;

#define CHAR_ACK '\x1F'
DEFINE_STRING(g_StrAck, "\x1F");

const char *ProcessSerial( void )
{
	int16_t av = Serial.available();
	if (av > 0)
	{
		for (int16_t i = 0; i < av; i++)
		{
			char ch = Serial.read();

			if (ch == CHAR_ACK)
			{
				// incomplete command. notify PC to send more
				Serial.println(g_StrAck);
				return NULL;
			}

			if (ch == '\n')
			{
				g_SerialBuffer[g_SerialBufferLen] = 0;
				g_SerialBufferLen = 0;
				if (Serial.available() == 0)
				{
					if (strcmp(g_SerialBuffer,"PEN") != 0 && strcmp(g_SerialBuffer,"BYE") != 0) // the initial handshake and BYE don't need ACK
					{
						Serial.println(g_StrAck);
					}
				}
				return g_SerialBuffer;
			}
			else if (g_SerialBufferLen < sizeof(g_SerialBuffer) - 1)
			{
				g_SerialBuffer[g_SerialBufferLen++] = ch;
			}
		}
	}

	return NULL;
}

// Parses the STATUS: string from the PC
// string format: <status>|workX,workY,workZ|feed%,rpm%,realFeed,realRpm
void ParseStatus( const char *status )
{
	g_MachineStatus = (MachineStatus)atol(status); status = strchr(status, '|') + 1;
	g_WorkX = atof(status); status = strchr(status, ',') + 1;
	g_WorkY = atof(status); status = strchr(status, ',') + 1;
	g_WorkZ = atof(status); status = strchr(status, '|') + 1;
	g_FeedOverride = atoi(status); status = strchr(status, ',') + 1;
	g_SpeedOverride = atoi(status); status = strchr(status, ',') + 1;
	g_RealFeed = atoi(status); status = strchr(status, ',') + 1;
	g_RealSpeed = atoi(status);
	status = strchr(status, '|');
	g_JobProgress = status ? atoi(status + 1) : -1;
}
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

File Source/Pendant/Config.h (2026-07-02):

#pragma once

// U8G2_FULL_BUFFER - Set to 1 to keep a copy of the screen buffer. Requires more RAM

// PARTIAL_SCREEN_UPDATE - Set to 1 to enable the optimization for redrawing only the modified portion of the screen.
//                         Greatly increses the framerate. Requires U8G2_FULL_BUFFER

// USE_NEW_ENCODER - Set to 1 to use the full NewEncoder library. Otherise a trimmed-down version of the code is used
//                   to save memory and reduce code dependencies. Requires modification to the NewEncoder library to support ATmega4808

// USE_WATCHDOG - Set to 1 to enable the WDT crash detection

// DISABLE_WELCOME_SCREEN, DISABLE_MACRO_SCREEN, DISABLE_CALIBRATION_SCREEN - disable individual screens to save memory
//         (for experiments that need more memory)

// DISABLE_ZPROBE_NUDGE - disable zprobe nudge to save memory

#if defined(__AVR_ATmega328P__) // Arduino Nano with ATmega328P

#define U8G2_FULL_BUFFER 0
#define PARTIAL_SCREEN_UPDATE 0
#define DISABLE_ZPROBE_NUDGE // Save some memory
#define USE_NEW_ENCODER 0 // You can set to 1 (for example to test a new wheel hardware), but it will disable some other features to save memory
#define USE_WATCHDOG 1

#if USE_NEW_ENCODER
// Disable few of the non-essential screens to free up some memory for the NewEncoder library
// To save even more memory, disable the macro U8G2_16BIT in U8g2\src\clib\u8g2.h
#define DISABLE_WELCOME_SCREEN
#define DISABLE_MACRO_SCREEN
#define DISABLE_CALIBRATION_SCREEN
#endif

#elif defined(__AVR_ATmega4809__) // Arduino Nano Every with ATmega4809

#define U8G2_FULL_BUFFER 1
#define PARTIAL_SCREEN_UPDATE 1
#define USE_NEW_ENCODER 1
#define USE_WATCHDOG 1

#elif defined(__AVR_ATmega4808__) // Arduino Nano Every clone with ATmega4808

#define U8G2_FULL_BUFFER 1
#define PARTIAL_SCREEN_UPDATE 1
#define USE_NEW_ENCODER 0 // NewEncoder doesn't recognize ATmega4808 out of the box. You need to modify interrupt_pins.h to get it to compile
#define USE_WATCHDOG 1

#elif defined(ARDUINO_NANO_R4)

#define U8G2_FULL_BUFFER 1
#define PARTIAL_SCREEN_UPDATE 1
#define USE_NEW_ENCODER 0 // NewEncoder doesn't recognize Nano R4 out of the box. The pins definitions are different
#define USE_WATCHDOG 1

#elif defined(_WIN32) // Pendant emulator

#define USE_WATCHDOG 0
#define EMULATOR
#define U8G2_FULL_BUFFER 1
#define PARTIAL_SCREEN_UPDATE 1

#else // Add support for more hardware here
#error "Unknown microcontroller"
#endif

#if PARTIAL_SCREEN_UPDATE && !U8G2_FULL_BUFFER
#error PARTIAL_SCREEN_UPDATE requires U8G2_FULL_BUFFER
#endif

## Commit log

2023-06-19 models
    Adding 3d models
    [Controlinator3000.step, cable_clamp_bottom.stl, cable_clamp_top.stl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]
2023-06-29 Dev (#6)
    * improved graphics
    * safer jog screen
    * advanced jogging
    * update
    * fixes
    * update
    [Config.h, Input.h, JogScreen.h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]
2023-06-30 Dev (#7)
    * fix jogging bug
    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
    [JogScreen.h, PendantMacro.js]
2023-07-06 Dev (#8)
    * fix for gcode macros
    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
    [PendantMacro.js]
2023-09-27 Dev (#9)
    * improved probing stability, show probe contact on pendant, show job duration on pendant
    * Add callback before entering the Job menu
    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
    [Main.h, PendantMacro.js, _ScreenClasses.h]
2025-08-11 Fix dialog bug
    A checklist could be dismissed by pressing an unassigned button
2025-08-11 Add Watchdog support
    The WDT will detect a reset due to software or hardware crash and notify the user.
    [Config.h, Main.h, Pendant.ino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]
2025-08-12 Dev (#11)
    * improvements
    improved probing stability, show probe contact on pendant, show job duration on pendant
    * Update PendantMacro.js
    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
2025-08-12 Dev (#12)
    * Update README.md
    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
2026-06-09 Update to v1.3
    * Few bug fixes
    * Job actions (run, pause, stop) are logged to the console
    * Improved diagnostics for disconnects and freezes
    [Main.h, PendantMacro.js, RunScreen.h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]
2026-06-10 Randomize probe position to reduce wear
2026-06-27 Support for Arduino Nano R4
    Adding support for Nano R4
    * connect to the display via Wire1 and the Qwiic port
    * use 16-bit pin registers in the wheel code
    * improved watchdog
    * split handshake into two separate commands to fix race condition in the serial communication
    [Config.h, Input.h, Main.h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]
2026-06-27 Connection and disconnection fixes
    [Main.h, PendantMacro.js]
2026-07-02 Version 1.5
    * Add ability to nudge the probing position with the joystick
    * Hold down Z to move up - useful for quickly raising the spindle out of the way
    * Remove jog workaround, no longer necessary for OpenBuilds v1.0.371
    * Show very small coordinates as 0
    [Config.h, JogScreen.h, Main.h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]
2026-07-06 Use number keys to emulate buttons
2026-10-29 Update for Groove Control
    Use jog services and machine limits if available
    New buttons in emulator for 20 wheel steps
2026-11-08 First pass at v2.0
    * Switch completely to Groove analogJog and mpgJog
    * Remove fake Openbuilds statuses
    * Switch to Nano R4 14-bit analog inputs
    * Add options to swap and invert joystick axes
